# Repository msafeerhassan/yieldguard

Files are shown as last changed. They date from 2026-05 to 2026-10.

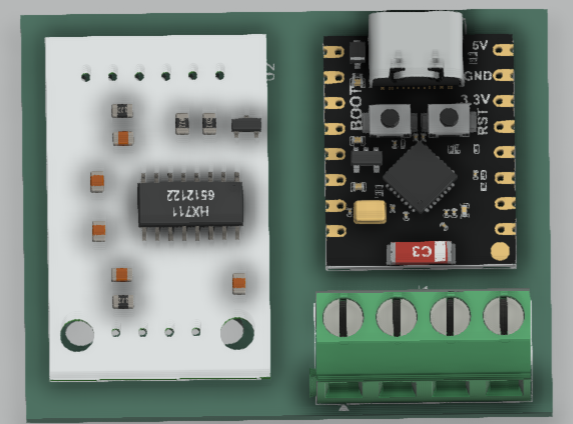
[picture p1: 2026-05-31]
Media/3D Image PCB.png

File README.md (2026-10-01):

# YieldGuard

## An automatic Milk Weight Logging System using ESP32, HX711 and Load Cell

### How it works:
1. The whole hardware sits under the milk collection Jar.
2. The milk gets collected inside the Jar - Hardware silently notices it.
3. When the milking completes, the weight becomes stable.
4. Once it stabilizes for more than 3 minutes, the milk weight gets logged and is sent over WhatsApp as a message.
5. It repeats :)

#### How to use it?

1. Go over to [JLCPCB](https://jlcpcb.com/).
2. Download the Gerber Files from this repository and upload them there and order PCB.
3. Use the links in BoM (Bill of Materials) to order other components (The 3D Case can either be 3D-Printed or pre-made case can be ordered).
4. Solder all the components on PCB and wire them properly as per the Schematic Diagram.
5. Connect ESP32 with your device and boot the Calibration Code in it.
6. Follow all the instructions mentioned in Serial Monitor to calibrate the Load Cell Specs etc.
7. Boot ESP32 with the main code given in Firmware/Main/main.ino file.
8. That's all :) Enjoy.

#### Why I built this?

I built this project to solve the real problem we faced at our farm - manual milk logging was quite difficult and unreliable. This automatic milk logging system makes the system highly reliable and efficient.

#### Screenshots:

PCB Design (2)
PCB Design (1)
Assembled Image 2
Assembled Image 1
3D Image PCB


#### Bill of Materials

| Item Name | Quantity | Link | Cost |
| :--- | :--- | :--- | :--- |
| ESP32-C3-SuperMini | 1 | https://epro.pk/product/esp32-c3-wireless-development-board-wifi-bluetooth/ | $2.53 |
| CZL-601 Aluminum Alloy 100kg Load Cell | 1 | https://www.aliexpress.com/item/1005007658937664.html | $13.00 |
| HX711 Module | 1 | https://epro.pk/product/arduino-load-cell-amplifier-hx711-hx-711-digital-scale/ | $0.60 |
| 2.54mm Pitch Female Pin Header Strip 40P | 2 | https://epro.pk/product/single-row-40pin-2-54mm-round-female-pin-header/ | $1.00 |
| Micro-USB Cable | 1 | https://epro.pk/product/micro-usb-cable-charger-for-android-cable-in-pakistan/ | $0.30 |
| 5V / 2A Phone Charger | 1 | https://www.daraz.pk/products/45-c-5v2a-pd-usb-i1956923074-s14016515229.html | $2.40 |
| 3D Case | 1 | https://epro.pk/product/waterproof-electronic-enclosure-box-150x110x75mm-4x6x3-inch-in-pakistan/ - Can be 3D Printed also | $1.00 |
| PCB | 5 | JLCPCB | $16 |
| AliExpress Taxes | - | - | $7.80 |
| ePro.Pk Shipping Charges | - | - | $1 |
| TOTAL COST | - | - | $50 |

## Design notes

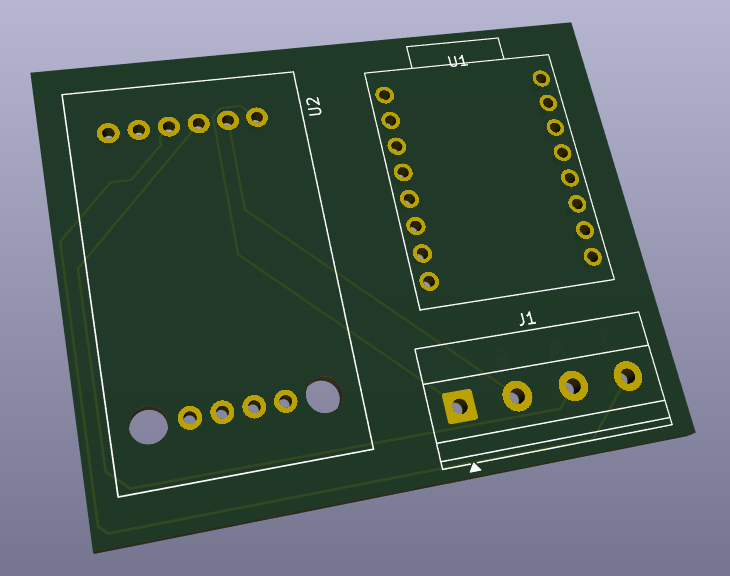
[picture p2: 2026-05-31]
Media/PCB Design (2).png

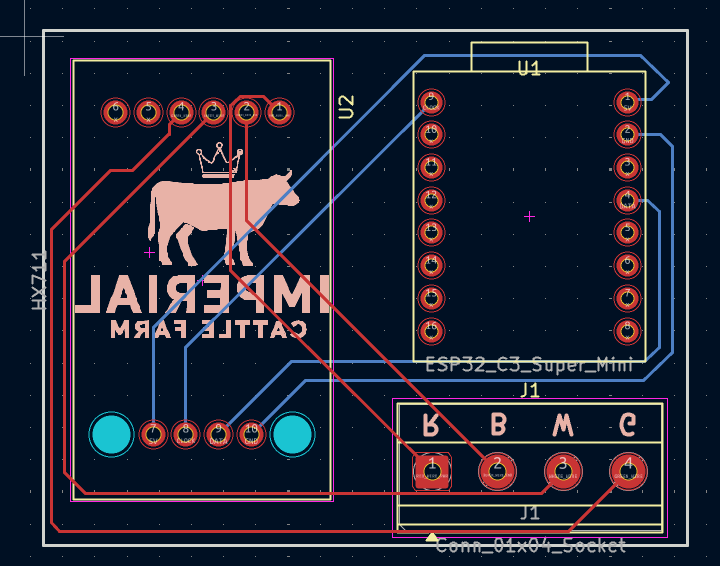
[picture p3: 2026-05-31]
Media/PCB Design (1).png

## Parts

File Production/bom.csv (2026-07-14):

Designator | Footprint | Quantity | Value | LCSC Part #
J1 | TerminalBlock_Phoenix_MKDS-1,5-4-5.08_1x04_P5.08mm_Horizontal | 1 | Conn_01x04_Socket
U1 | ESP32-C3_SuperMini | 1 | ESP32_C3_Super_Mini
U2 | HX711_module | 1 | HX711

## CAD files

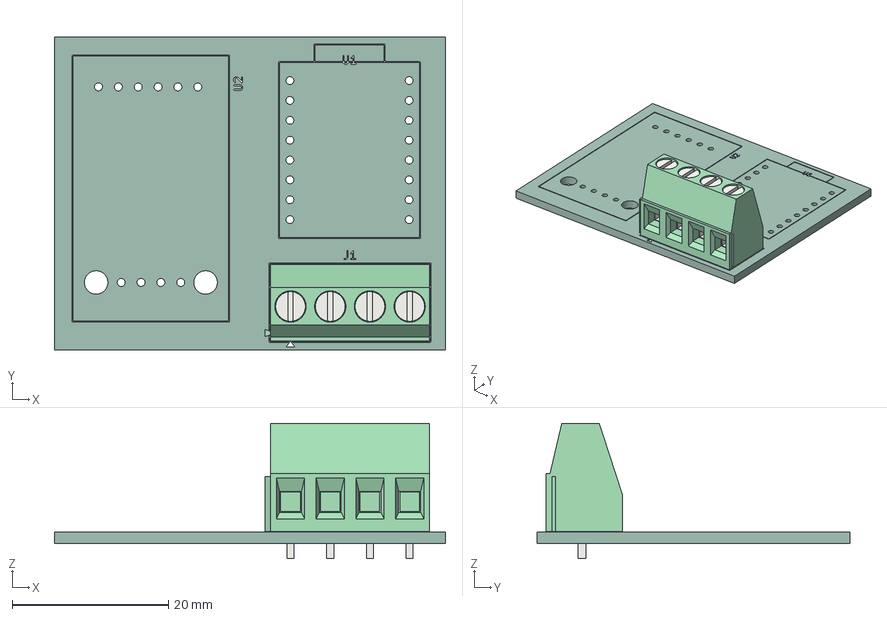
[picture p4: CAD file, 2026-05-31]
CAD/PCB.step
50.0 x 40.0 x 17.3 mm
TerminalBlock_Phoenix_MKDS-1,5-4-5.08_1x04_P5.08mm_Horizontal
YieldGuard_silkscreen x 2
YieldGuard_PCB

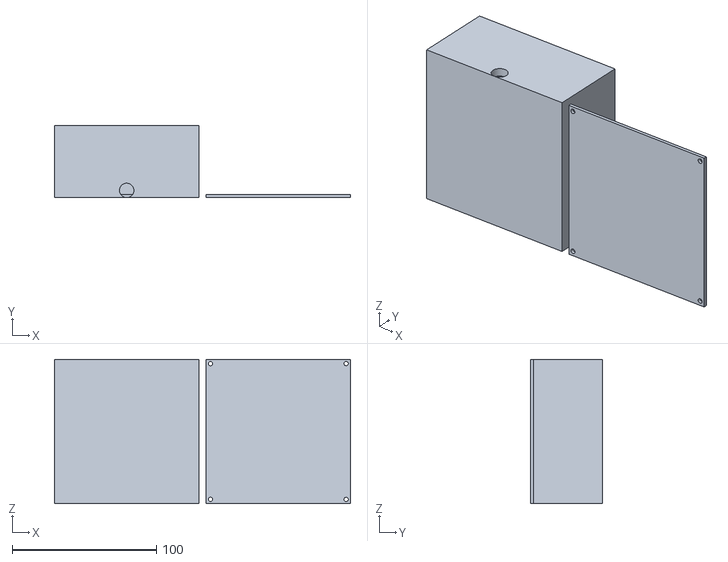
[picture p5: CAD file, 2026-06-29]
Production/Case Design.stl
205.0 x 50.0 x 100.0

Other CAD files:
CAD/Case.step

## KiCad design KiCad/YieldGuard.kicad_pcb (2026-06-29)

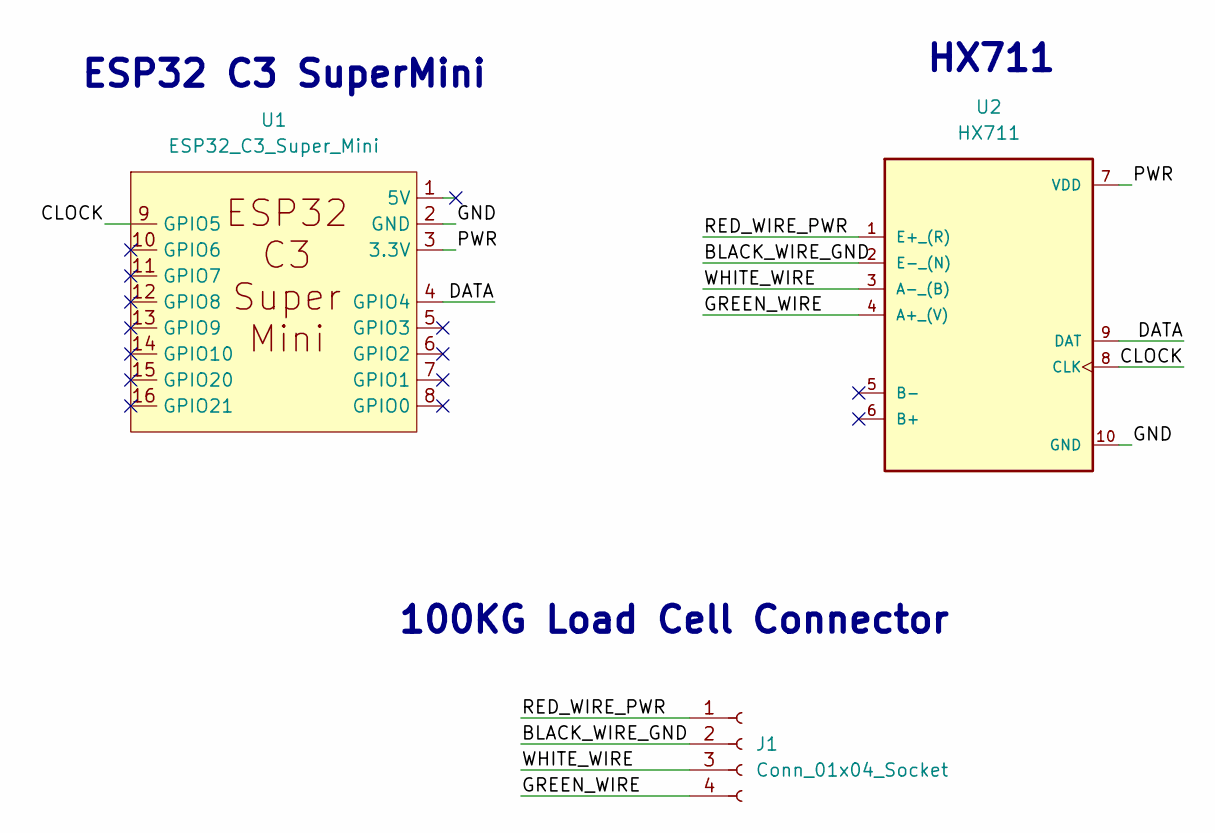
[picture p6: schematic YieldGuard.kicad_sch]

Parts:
J1: Conn_01x04_Socket; TerminalBlock_Phoenix_MKDS-1,5-4-5.08_1x04_P5.08mm_Horizont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
U1: ESP32_C3_Super_Mini; ESP32-C3_SuperMini
U2: HX711; HX711_module

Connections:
/BLACK_WIRE_GND: J1.2, U2.2 (E-_(N))
/CLOCK: U1.9 (GPIO5), U2.8 (CLK)
/DATA: U1.4 (GPIO4), U2.9 (DAT)
/GND: U1.2 (GND), U2.10 (GND)
/GREEN_WIRE: J1.4, U2.4 (A+_(V))
/PWR: U1.3 (3.3V), U2.7 (VDD)
/RED_WIRE_PWR: J1.1, U2.1 (E+_(R))
/WHITE_WIRE: J1.3, U2.3 (A-_(B))

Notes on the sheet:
HX711
ESP32 C3 SuperMini
100KG Load Cell Connector

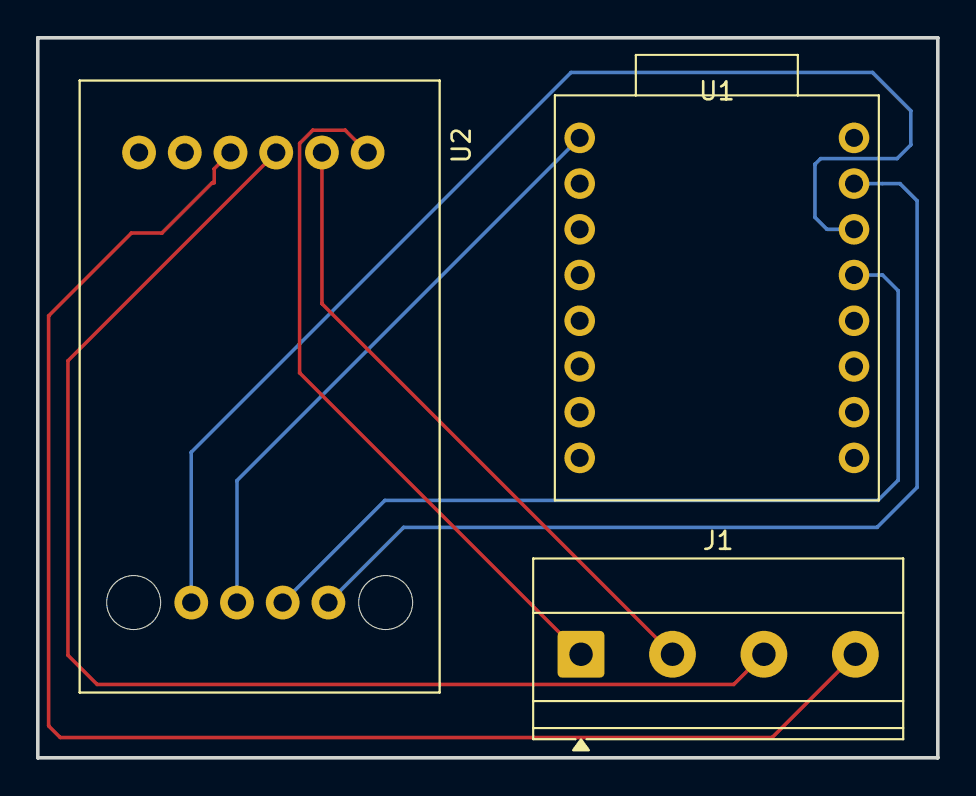
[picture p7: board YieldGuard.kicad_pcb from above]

Board: 2 copper layers, 50.0 x 40.0 mm, 3 parts (0 on the bottom side), 8 nets.

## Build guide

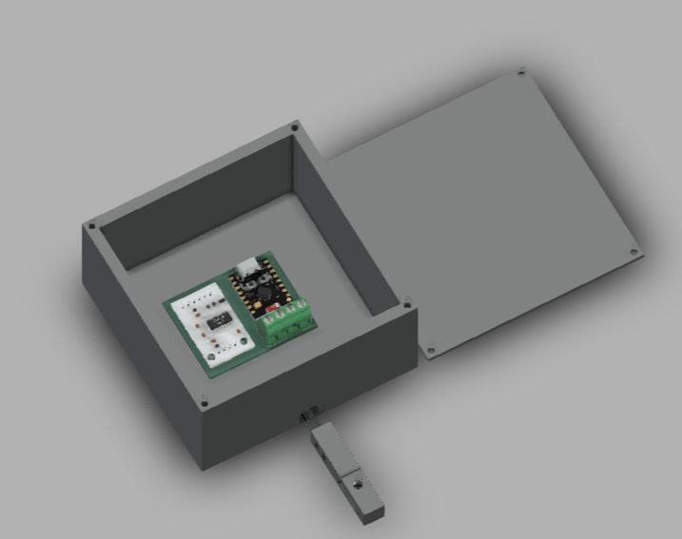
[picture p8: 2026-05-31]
Media/Assembled Image 2.png

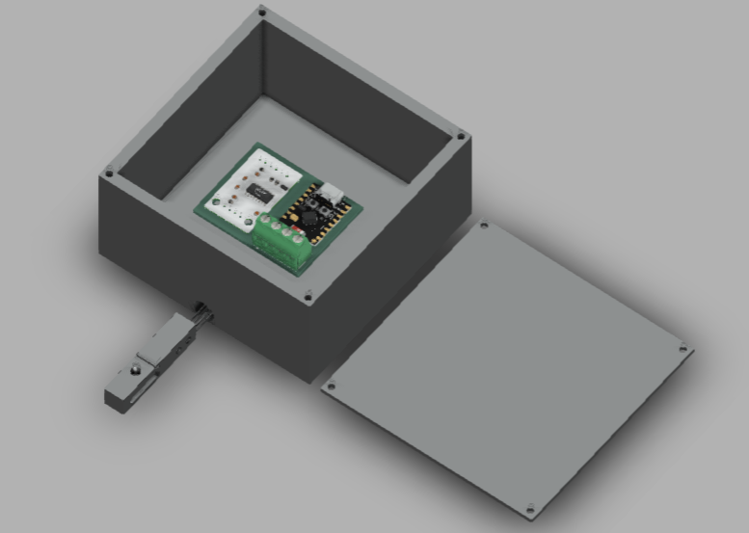
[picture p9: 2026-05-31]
Media/Assembled Image 1.png

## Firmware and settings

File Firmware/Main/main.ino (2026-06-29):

#include <Arduino.h>
#include <WiFi.h>
#include <HTTPClient.h>
#include <UrlEncode.h>
#include <HX711.h>

#define WIFI_SSID "NetworkName"
#define WIFI_PASSWORD "NetworkPassword"
#define WHATSAPP_NUMBER "WhatsAppNumberForAlerts"
#define CALLMEBOT_APIKEY "APIKEY"

#define HX711_DOUT_PIN 4
#define HX711_SCK_PIN 5

#define LOADCELL_OFFSET 50682624L
#define LOADCELL_FACTOR 5895.6550f

#define STABILITY_TOLERANCE 100.0f
#define STABILITY_DURATION (3UL * 60UL * 1000UL)
#define MIN_WEIGHT_TO_TRACK 100.0f
#define INTERVAL_MS 1000UL

HX711 scale;

float refWeight = 0.0f;
unsigned long stableSince = 0;
bool isTrackingStability = false;
bool alertSent = false;
unsigned long lastSample = 0;

void connectWifi() {
    WiFi.mode(WIFI_STA);
    WiFi.begin(WIFI_SSID, WIFI_PASSWORD);
    unsigned long start = millis();

    while (WiFi.status() != WL_CONNECTED) {
        delay(300);
        if (millis() - start > 20000) {
            WiFi.disconnect();
            delay(500);
        WiFi.begin(WIFI_SSID, WIFI_PASSWORD);
        start = millis();
        }
    }

    Serial.print("WiFi Connected. IP: ");
    Serial.println(WiFi.localIP());
}

void ensureWifi() {
    if (WiFi.status() != WL_CONNECTED) connectWifi();
}

bool sendWhatsappMsg(const String &message) {
    ensureWifi();
    String url = "https://api.callmebot.com/whatsapp.php?phone=" + String(WHATSAPP_NUMBER) +
               "&apikey=" + String(CALLMEBOT_APIKEY) + "&text=" + urlEncode(message);
    HTTPClient http;
    http.begin(url);
    http.addHeader("Content-Type", "application/x-www-form-urlencoded");
    int httpResponseCode = http.GET();
    bool success = (httpResponseCode == 200);
    Serial.println(success ? "Whatsapp Message Sent." : "Failed to send message");
    http.end();
    return success;
}

void setupLoadCell() {
    scale.begin(HX711_DOUT_PIN, HX711_SCK_PIN);
    scale.wait_ready_timeout(3000);
    scale.set_offset(LOADCELL_OFFSET);
    scale.set_scale(LOADCELL_FACTOR);
}

float readWeight() {
    if (!scale.wait_ready_timeout(500)) return NAN;
    return scale.get_units(5);
}

void resetStabilityTracking(float newRef) {
    refWeight = newRef;
    stableSince = millis();
    isTrackingStability = true;
    alertSent = false;
}

void clearStabilityTracking() {
    isTrackingStability = false;
    alertSent = false;
}

void handleNewReading(float weight) {
    if (weight < MIN_WEIGHT_TO_TRACK) {
        clearStabilityTracking();
        return ;
    }

    if (!isTrackingStability) {
        resetStabilityTracking(weight);
        return ;
    }

    float delta = fabs(weight - refWeight);

    if (delta <= STABILITY_TOLERANCE) {
        unsigned long stableFor = millis() - stableSince;

        if (!alertSent && stableFor >= STABILITY_DURATION) {
            char msg[160];
            snprintf(msg, sizeof(msg), "YeildGuard Alert: Weight Stabilized at %.1f g for %lu minutes", refWeight, (unsigned long)(STABILITY_DURATION / 60000UL));
            Serial.println(msg);
            sendWhatsappMsg(String(msg));
            alertSent = true;
        }
    }
    else {
        resetStabilityTracking(weight);
    }
}

void setup() {
    Serial.begin(115200);
    unsigned long start = millis();
    while (!Serial && millis() - start < 3000) delay(10);

    setupLoadCell();
    connectWifi();
}


void loop() {
    unsigned long now = millis();
    if (now - lastSample >= INTERVAL_MS) {
        lastSample = now;
        float weight = readWeight();
        if (isnan(weight)) return;

        Serial.print("Weight: ");
        Serial.println(weight, 1);

        handleNewReading(weight);
    }
}

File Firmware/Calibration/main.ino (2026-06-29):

#include <Arduino.h>
#include <HX711.h>

const int HX711_DOUT_PIN = 4;
const int HX711_SCK_PIN = 5;

HX711 scale;

void printMenu() {
    Serial.println();
    Serial.println("t = Tare, r = raw Reading, c = calibrate, w = weight, ? = Menu");
}

void setup() {
    Serial.begin(115200);
    unsigned long start = millis();
    while (!Serial && millis() - start < 3000)
    {
        delay(10);
    }

    scale.begin(HX711_DOUT_PIN, HX711_SCK_PIN);
    
    if (scale.wait_ready_timeout(2000)) {
        Serial.println("HX711 Found.");
    }
    else {
        Serial.println("HX711 Missing - Please check wiring");
    }

    scale.set_scale();
    scale.set_offset(0);
    printMenu();

    Serial.println("Remove all weight and then sent 't' to tare.");
}

void tare() {
    scale.tare(20);
    Serial.println("Tare Complete. Offset = ");
    Serial.println(scale.get_offset());
}

void showRaw() {
    if (!scale.wait_ready_timeout(1000)) {
        Serial.println("HX711 not ready");
        return ;
    }
    Serial.println("Raw Reading: ");
    Serial.println(scale.get_value(10));
}

void calibrate() {
    Serial.println("Place know weight and then type it in grams and hit Enter: ");

    while (!Serial.available()) {
        delay(50);
    }

    String input = Serial.readStringUntil('\n');
    input.trim();

    float knowWeight = input.toFloat();

    if (knowWeight <= 0) {
        Serial.println("Invalid Weight.");
        return ;
    }

    long rawValue = scale.get_value(20);

    if (rawValue == 0) {
        Serial.println("Raw Reading was 0 - check circuit please");
        return ;
    }

    float calibrationFactor = (float)rawValue / knowWeight;

    Serial.print("Load Cell Offset = ");
    Serial.println(scale.get_offset());
    Serial.print("Load Cell Factor = ");
    Serial.println(calibrationFactor, 4);

    scale.set_scale(calibrationFactor);
    Serial.println("Send 'w' to verify");
}

void showWeight() {
    if (!scale.wait_ready_timeout(1000)) {
        Serial.println("HX711 not ready");
        return ;
    }

    Serial.print("Weight: ");
    Serial.print(scale.get_units(10), 1);
    Serial.println(" g");
}


void loop() {
    if(Serial.available()) {
        char c = Serial.read();

        switch (c)
        {
            case 't' : case 'T' : tare(); break;
            case 'r' : case 'R' : showRaw(); break;
            case 'c' : case 'C' : calibrate(); break;
            case 'w' : case 'W' : showWeight(); break;
            case '?' : printMenu(); break;
        }
    }

    delay(20);
}

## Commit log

2026-05-24 Adding draft BoM
    [Bill of Materials.xlsx]
2026-05-24 Add KiCad files - schematic complete
    [Bill of Materials.xlsx, YieldGuard.kicad_pcb, YieldGuard.kicad_sch]
2026-05-25 added complete pcb design with gerber files
    [YieldGuard.kicad_pcb, YieldGuard.kicad_sch]
2026-05-25 rounded pcb corners - final touch to the pcb
    [YieldGuard.kicad_pcb]
2026-05-25 fixed the dimension of screw terminal of load cell
    [YieldGuard.kicad_pcb]
2026-05-25 Bit changes in PCB and Schematic and Completed BoM
    [Bill of Materials.xlsx, YieldGuard.kicad_pcb, YieldGuard.kicad_sch]
2026-05-26 routed updated PCB
    [YieldGuard.kicad_pcb]
2026-05-31 finished BoM, PCB, 3D
    [Bill of Materials.csv, Bill of Materials.xlsx, Case.step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]
2026-06-29 added firmware and improved bom and readme
    [Bill of Materials.csv]
2026-06-29 added stl file
    [Case Design.stl]
2026-06-29 kicad fixes
    [YieldGuard.kicad_pcb, YieldGuard.kicad_sch]
2026-07-14 added pcb csv details files
    [bom.csv, designators.csv, positions.csv]
2026-08-03 added production folder + files
    [Case Design.stl, bom.csv, designators.csv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]
2026-10-01 updated Bom
    [Bill of Materials.csv]
